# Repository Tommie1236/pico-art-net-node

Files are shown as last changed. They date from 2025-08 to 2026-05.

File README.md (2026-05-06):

# !! working on v2. the main branch is deprecated if you see this message. please go to [the V2 branch](https://github.com/Tommie1236/pico-art-net-node/tree/V2).



# pico-art-net-node

got the idea from the project linked below. took some ideas/parts off it and created my own one 

https://www.techandtransit.com/lighting/pi-pico-artnet-to-dmx-node  
https://github.com/tmingos/Pico-ArtNet-DMX-Node

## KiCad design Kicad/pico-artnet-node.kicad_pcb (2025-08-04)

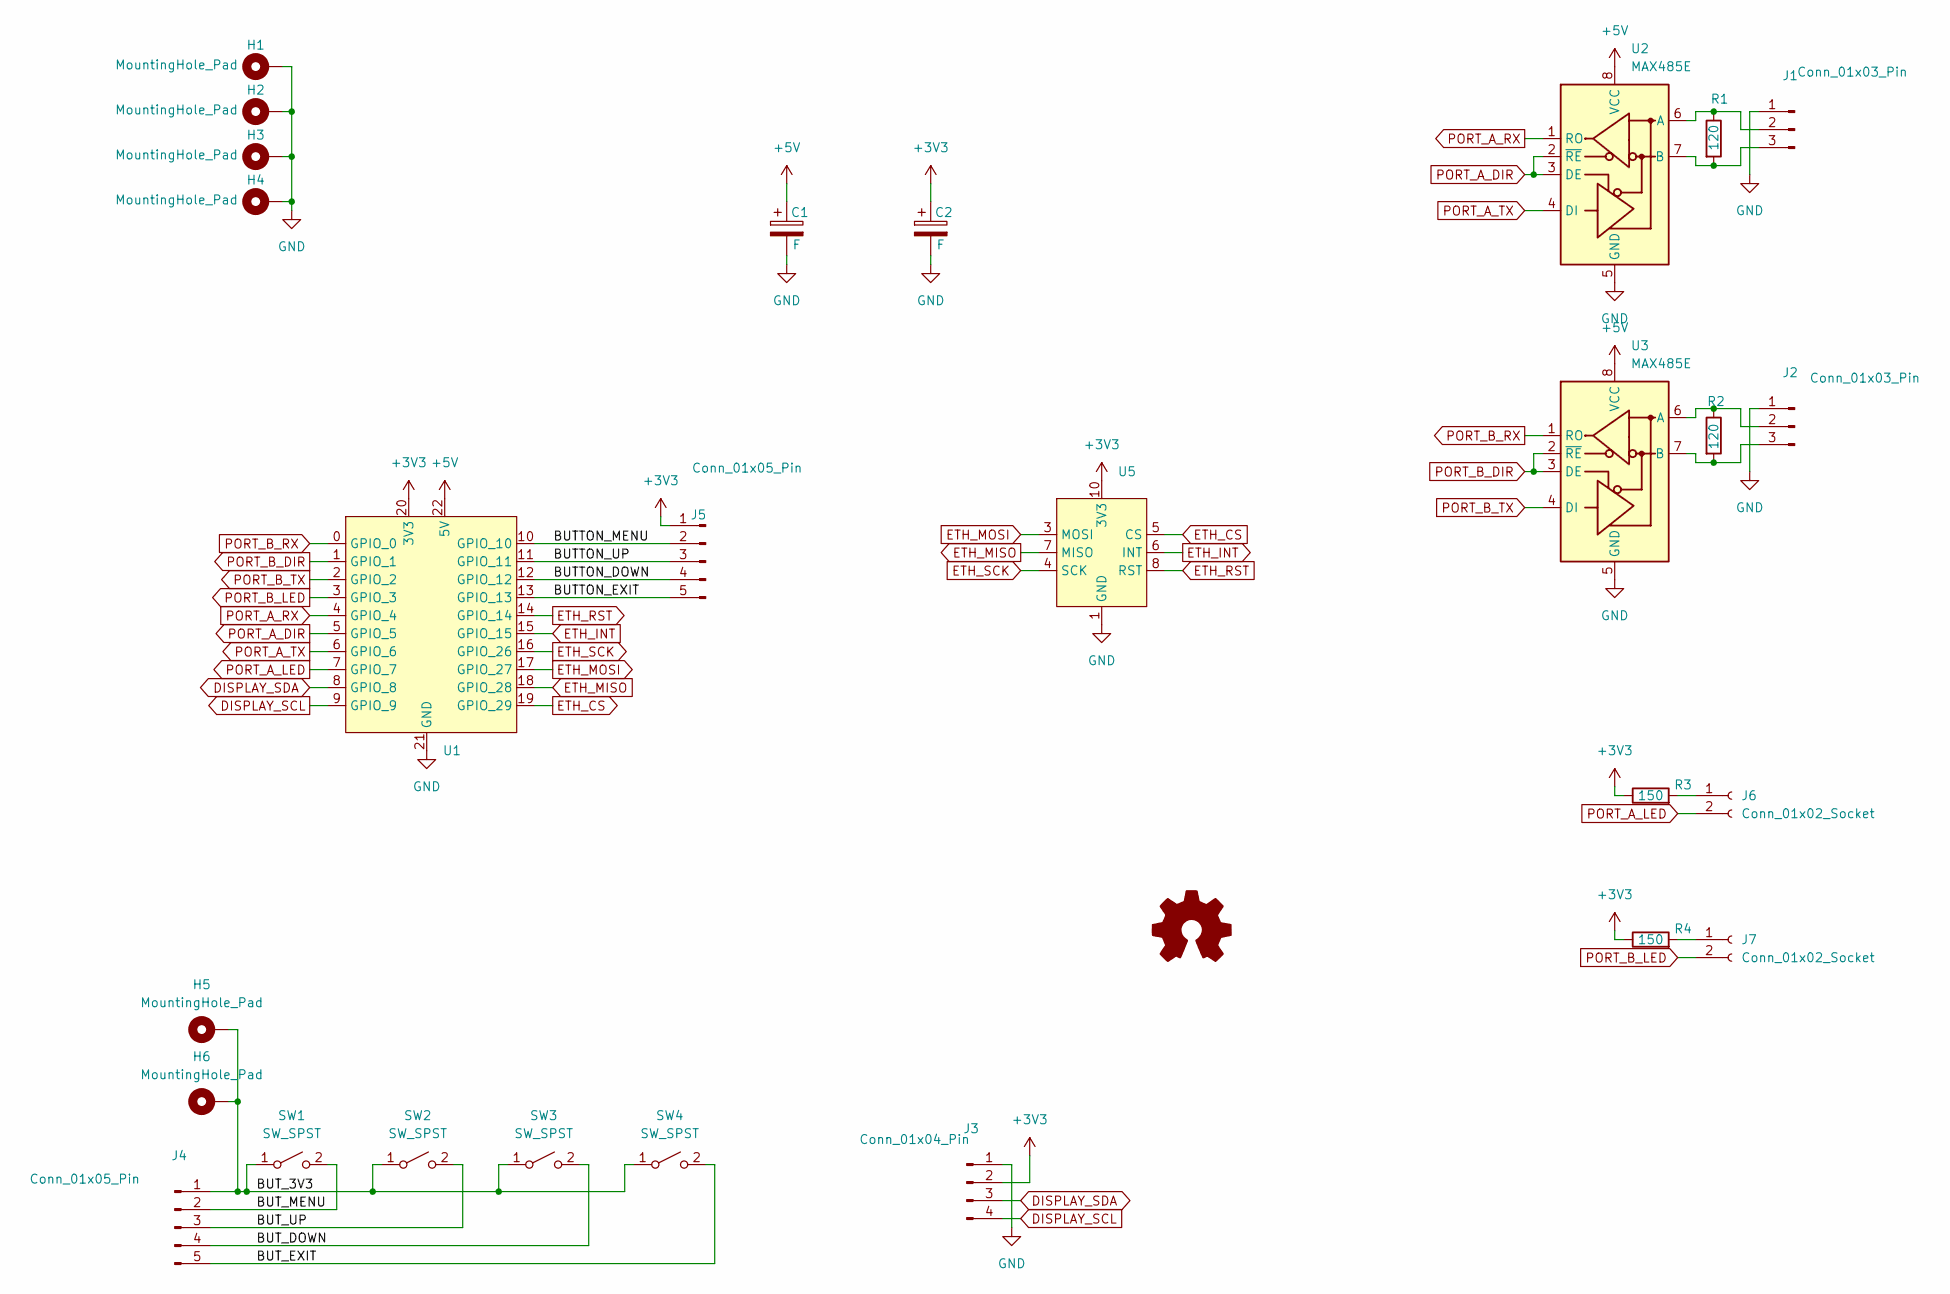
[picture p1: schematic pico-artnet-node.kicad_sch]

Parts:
C1, C2: F; CP_Radial_D5.0mm_P2.50mm
H1, H2, H3, H4, H5, H6: MountingHole_Pad; MountingHole_3.2mm_M3_DIN965_Pad
J1, J2: Conn_01x03_Pin; PinHeader_1x03_P2.54mm_Vertical
J3: Conn_01x04_Pin; PinHeader_1x04_P2.54mm_Vertical
J4, J5: Conn_01x05_Pin; PinHeader_1x05_P2.54mm_Vertical
J6, J7: Conn_01x02_Socket; PinHeader_2x01_P2.54mm_Vertical
R1, R2: 120; R_Axial_DIN0207_L6.3mm_D2.5mm_P2.54mm_Vertical
R3, R4: 150; R_Axial_DIN0207_L6.3mm_D2.5mm_P2.54mm_Vertical
SW1, SW2, SW3, SW4: SW_SPST; SW_PUSH_6mm
SYM2: Logo_Open_Hardware_Small; OSHW-Logo2_14.6x12mm_SilkScreen
U1: RP2040-Zero
U2, U3: MAX485E; DIP-8_W7.62mm
U5: w5500

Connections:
+3V3: C2.1, J3.2, J5.1, R3.1, R4.1, U1.20 (3V3), U5.10 (3V3), U5.11 (3V3)
+5V: C1.1, U1.22 (5V), U2.8 (VCC), U3.8 (VCC)
/BUTTON_DOWN: J5.4, U1.12 (GPIO_12)
/BUTTON_EXIT: J5.5, U1.13 (GPIO_13)
/BUTTON_MENU: J5.2, U1.10 (GPIO_10)
/BUTTON_UP: J5.3, U1.11 (GPIO_11)
/BUT_3V3: H5.1, H6.1, J4.1, SW1.1 (A), SW2.1 (A), SW3.1 (A), SW4.1 (A)
/BUT_DOWN: J4.4, SW3.2 (B)
/BUT_EXIT: J4.5, SW4.2 (B)
/BUT_MENU: J4.2, SW1.2 (B)
/BUT_UP: J4.3, SW2.2 (B)
DISPLAY_SCL: J3.4, U1.9 (GPIO_9)
DISPLAY_SDA: J3.3, U1.8 (GPIO_8)
ETH_CS: U1.19 (GPIO_29), U5.5 (CS)
ETH_INT: U1.15 (GPIO_15), U5.6 (INT)
ETH_MISO: U1.18 (GPIO_28), U5.7 (MISO)
ETH_MOSI: U1.17 (GPIO_27), U5.3 (MOSI)
ETH_RST: U1.14 (GPIO_14), U5.8 (RST)
ETH_SCK: U1.16 (GPIO_26), U5.4 (SCK)
GND: C1.2, C2.2, H1.1, H2.1, H3.1, H4.1, J1.1, J2.1, J3.1, U1.21 (GND), U2.5 (GND), U3.5 (GND), U5.1 (GND), U5.2 (GND), U5.12 (GND)
unnamed: J1.2, R1.1, U2.6 (A)
unnamed: J1.3, R1.2, U2.7 (B)
unnamed: J2.2, R2.1, U3.6 (A)
unnamed: J2.3, R2.2, U3.7 (B)
unnamed: J6.1, R3.2
unnamed: J7.1, R4.2
PORT_A_DIR: U1.5 (GPIO_5), U2.2 (~RE), U2.3 (DE)
PORT_A_LED: J6.2, U1.7 (GPIO_7)
PORT_A_RX: U1.4 (GPIO_4), U2.1 (RO)
PORT_A_TX: U1.6 (GPIO_6), U2.4 (DI)
PORT_B_DIR: U1.1 (GPIO_1), U3.2 (~RE), U3.3 (DE)
PORT_B_LED: J7.2, U1.3 (GPIO_3)
PORT_B_RX: U1.0 (GPIO_0), U3.1 (RO)
PORT_B_TX: U1.2 (GPIO_2), U3.4 (DI)

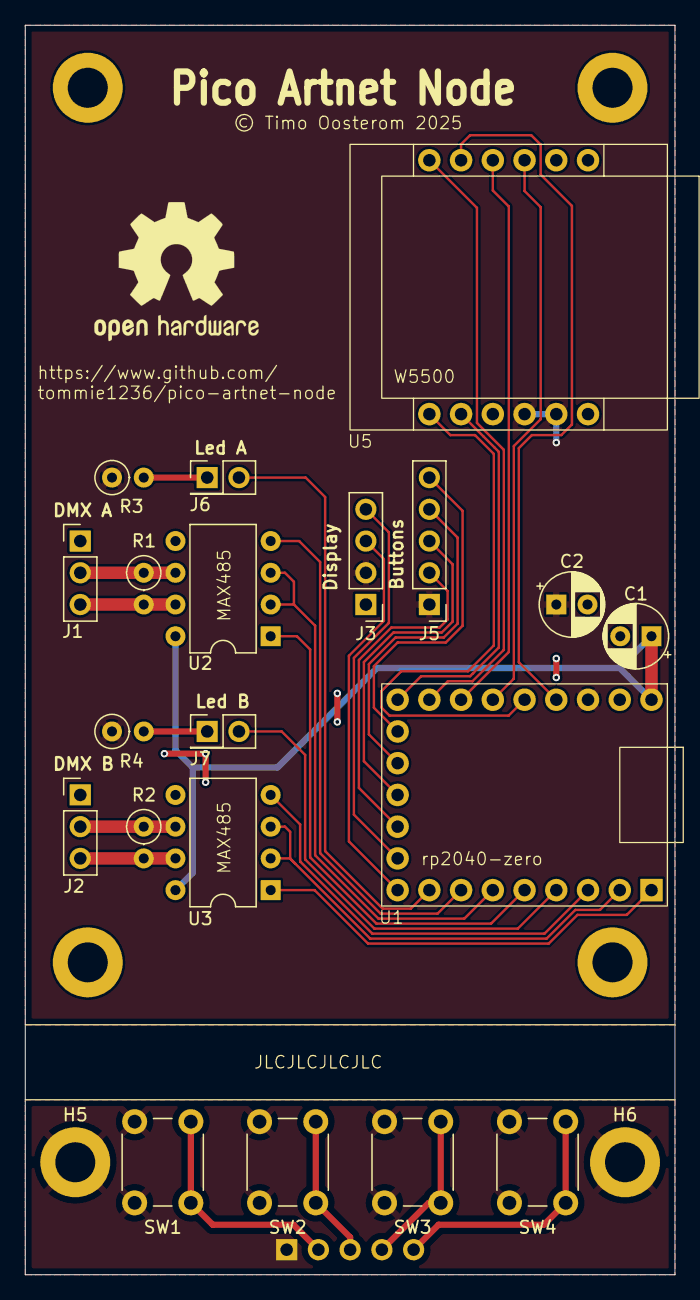
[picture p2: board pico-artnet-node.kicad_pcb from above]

Board: 2 copper layers, 52.0 x 100.0 mm, 28 parts (1 on the bottom side), 34 nets.

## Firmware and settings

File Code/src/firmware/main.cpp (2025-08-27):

#include <stdio.h>
#include <string>
#include <vector>
#include <unordered_map>
#include <variant>
#include <array>
#include <cstdio>

#include "hardware/gpio.h"
#include "hardware/i2c.h"
#include "hardware/spi.h"
#include "pico/stdlib.h"
#include "pico/time.h"
#include "pico/multicore.h"
#include "pico/unique_id.h"

#include "main.h"

#define _WIZCHIP_ W5500
#include "W5500/w5500.h"
#include "wizchip_conf.h"
#include "socket.h"

#include <DmxOutput.h>
//#include <DmxInput.h>
// Dmx input maybe be supported in the future. for now only output.
#include <ssd1306.h>
#include <textRenderer/TextRenderer.h>
#include <shapeRenderer/ShapeRenderer.h>


using namespace pico_ssd1306;

#define FONT font_12x16 

enum MENU_PAGE {
    MAIN,
    NETWORK,
    IP,
    DHCP, 
//    DHCP_STATIC,
    PORTS,
    A,
    A_STATUS,
    A_UNIVERSE,
    B,
    B_STATUS,
    B_UNIVERSE,
    STATUS,
    LOCK            // TODO: Lock/unlock the menu by holding the menu button for 3 seconds.
};

enum PORT_STATUS {
    INPUT,
    OUTPUT,
    DISABLED
};

using ConfigTypes = std::variant<bool, std::array<uint8_t, 4>, uint16_t, PORT_STATUS>;

std::unordered_map<std::string, ConfigTypes> config = {
    {"IP", std::array<uint8_t, 4>{2, 0, 0, 1}},
    {"SUBNET", std::array<uint8_t, 4>{255, 0, 0, 0}},
    {"DHCP", true},
    {"PORT_A_STATUS", PORT_STATUS::OUTPUT},
    {"PORT_A_UNIVERSE", uint16_t(0x0000)},
    {"PORT_B_STATUS", PORT_STATUS::OUTPUT},
    {"PORT_B_UNIVERSE", uint16_t(0x0001)}
};

//DmxOutput dmx_out[2];
//DmxInput  dmx_in[2];


//uint8_t universe_A[UNIVERSE_LENGTH + 1];
//uint8_t universe_B[UNIVERSE_LENGTH + 1];



// Menu structure (https://www.tldraw.com/ro/jS2uV4zSO97DEFvRHu4y5)
//
// MAIN 
//  - Network
//      - ip
//          ip: 002.000.000.001
//          sn: 255.000.000.000
//      - dhcp
//          enable  [ ]
//          disable [x]
//  - Ports
//      - A
//      - B
//          - status
//              output
//              input
//              disabled  
//          - universe
//              net
//              subnet
//              universe
//  - Status ??
//
//


void ip_to_str(std::array<uint8_t, 4> ip, char *ip_str) {
    sprintf(ip_str, "%03d.%03d.%03d.%03d", ip[0], ip[1], ip[2], ip[3]);
}


void init_gpio() {

    uint32_t mask_all = 0;
    mask_all |= (1 << PORT_A_DIR_PIN);
    mask_all |= (1 << PORT_A_LED_PIN);
    mask_all |= (1 << PORT_B_DIR_PIN);
    mask_all |= (1 << PORT_B_LED_PIN);
    mask_all |= (1 << MENU_BUTTON_PIN);
    mask_all |= (1 << UP_BUTTON_PIN);
    mask_all |= (1 << DOWN_BUTTON_PIN);
    mask_all |= (1 << EXIT_BUTTON_PIN);
    mask_all |= (1 << ETH_INT_PIN);
    mask_all |= (1 << ETH_RST_PIN);

    uint32_t mask_inp = 0;
    mask_inp |= (1 << MENU_BUTTON_PIN);
    mask_inp |= (1 << UP_BUTTON_PIN);
    mask_inp |= (1 << DOWN_BUTTON_PIN);
    mask_inp |= (1 << EXIT_BUTTON_PIN);
    mask_inp |= (1 << ETH_INT_PIN);

    // all pins are used so all that arent input are output
    uint32_t mask_out = mask_all & ~mask_inp;

    gpio_init_mask(mask_all);
    gpio_set_dir_in_masked(mask_inp);
    gpio_set_dir_out_masked(mask_out);

    // there is no masked version of pullup/down.
    gpio_pull_up(MENU_BUTTON_PIN);
    gpio_pull_up(UP_BUTTON_PIN);
    gpio_pull_up(DOWN_BUTTON_PIN);
    gpio_pull_up(EXIT_BUTTON_PIN);
    gpio_pull_up(ETH_INT_PIN);     // how add interrupt? change when adding ethernet 

    gpio_put(PORT_A_LED_PIN, 1);
    gpio_put(PORT_B_LED_PIN, 1);
    // set to highest power. seems to not work with less
    gpio_set_drive_strength(PORT_A_LED_PIN, GPIO_DRIVE_STRENGTH_12MA);
    gpio_set_drive_strength(PORT_B_LED_PIN, GPIO_DRIVE_STRENGTH_12MA);
}

void init_oled() {
    i2c_init(i2c0, 1000 * 1000);        
    //i2c_init(i2c0, 3960 * 1000);        // 3.96 MHz. (ssd1306 is max 10Mhz but this is the limit for my module.)

    gpio_set_function(DISPLAY_SDA_PIN, GPIO_FUNC_I2C);
    gpio_set_function(DISPLAY_SCL_PIN, GPIO_FUNC_I2C);

    gpio_pull_up(DISPLAY_SDA_PIN);
    gpio_pull_up(DISPLAY_SCL_PIN);
}

void draw_menu_content(pico_ssd1306::SSD1306 *ssd1306, std::string title, std::vector<std::string> content, bool clear = true) {
    if (clear) {
        ssd1306->clear();
    }
    drawLine(ssd1306, 0, 15, 128, 15);

    // Draw the title
    drawText(ssd1306, FONT, title.c_str(), 0, 0);
    
    // Draw the menu items
    for (uint8_t i = 0; (i < content.size()) & (i < 3); ++i) {
        drawText(ssd1306, FONT, content[i].c_str(), 0, 16 + i * 16);
    }
}

void draw_menu_selected(pico_ssd1306::SSD1306 *ssd1306, uint8_t selected) {
    fillRect(ssd1306, 0, 16 + selected * 16, 128, 31 + selected * 16, WriteMode::INVERT);
}

void draw_menu(
    pico_ssd1306::SSD1306 *ssd1306,
    std::string title,
    std::vector<std::string> content,
    uint8_t selected,
    bool sendBuffer = true
){
    draw_menu_content(ssd1306, title, content);
    draw_menu_selected(ssd1306, selected);

    if (sendBuffer) {
        ssd1306->sendBuffer();
    }
}

void switch_menu(
    MENU_PAGE &current_page,
    MENU_PAGE new_page,
    uint8_t &current_selection
){
    current_page = new_page;
    current_selection = 0;
}


uint8_t wizchip_spi_read(void) {
    uint8_t data;
    spi_read_blocking(ETH_SPI, 0xff, &data, 1);
    return data;
}

void wizchip_spi_write(uint8_t data) {
    spi_write_blocking(ETH_SPI, &data, 1);
}

void wizchip_cs_select(void) {
    gpio_put(ETH_CS_PIN, 0);
}

void wizchip_cs_deselect(void) {
    gpio_put(ETH_CS_PIN, 1);
}


void init_w5500(void) {
    // TODO: check for duplicate pin inits, this is just for a test

    gpio_init(ETH_RST_PIN);
    gpio_set_dir(ETH_RST_PIN, GPIO_OUT);
    gpio_put(ETH_RST_PIN, 0);
    sleep_ms(10);
    gpio_put(ETH_RST_PIN, 1);
    sleep_ms(50);

    spi_init(ETH_SPI, 10 * 1000 * 1000); // 10MHz
    spi_set_format(ETH_SPI, 8, SPI_CPOL_0, SPI_CPHA_0, SPI_MSB_FIRST);
    gpio_set_function(ETH_SCK_PIN, GPIO_FUNC_SPI);
    gpio_set_function(ETH_MOSI_PIN, GPIO_FUNC_SPI);
    gpio_set_function(ETH_MISO_PIN, GPIO_FUNC_SPI);

    gpio_init(ETH_CS_PIN);
    gpio_set_dir(ETH_CS_PIN, GPIO_OUT);
    gpio_put(ETH_CS_PIN, 1);

    reg_wizchip_spi_cbfunc(wizchip_spi_read, wizchip_spi_write);
    reg_wizchip_cs_cbfunc(wizchip_cs_select, wizchip_cs_deselect);

    uint8_t tx_rx_mem[2][8] = { {2,2,2,2,2,2,2,2}, {2,2,2,2,2,2,2,2}};
    
    wizchip_init(tx_rx_mem[0], tx_rx_mem[1]);

    wiz_NetInfo netinfo = {
        .ip = {192, 168, 2, 80},
        .sn = {255, 255, 255, 0},
        .gw = {192, 168, 2, 254},
        .dns = {1, 1, 1, 1},
        .dhcp = NETINFO_STATIC
    };

    // set mac from flash serial to always be unique
    pico_unique_board_id_t id;
    pico_get_unique_board_id(&id);

    memcpy(netinfo.mac, id.id, 6);
    netinfo.mac[0] = (netinfo.mac[0] & 0xfe ) | 0x02;
    
    wizchip_setnetinfo(&netinfo);

}



void main_core_1 () {
    // TODO:
    // handle artnet connection and send the dmx data to the pio's
    // input isn't supported yet. only output.
    DmxOutput dmx_out0 = DmxOutput();
    DmxOutput dmx_out1 = DmxOutput();

    // set port A to output for now
    gpio_put(PORT_A_DIR_PIN, 1);
    gpio_put(PORT_B_DIR_PIN, 1);

    dmx_out0.begin(PORT_A_TX_PIN);
    dmx_out1.begin(PORT_B_TX_PIN);

    socket(0, Sn_MR_UDP, 6454, 0);
    printf("socket connected\n");


    uint8_t buf[600];

    while (true) {

        int32_t len = recvfrom(0, buf, sizeof(buf), NULL, NULL);

        if (len > 0 && len >= 18 && memcmp(buf, "Art-Net\0", 8) == 0) {
            uint16_t opcode = buf[8] | (buf[9] << 8);

            if (opcode == 0x5000) {
                //uint16_t length = (buf[16] << 8) | buf[17];
                uint16_t universe = buf[14] | (buf[15] << 8);

                static uint8_t dmx_frame[513];
                dmx_frame[0] = 0;   // start byte
                memcpy(dmx_frame + 1, buf + 18, 512);

                if (universe == 0) {
                    gpio_put(PORT_A_LED_PIN, 0);    // Dmx Status Led On
                    dmx_out0.write(dmx_frame, 513);
                    while (dmx_out0.busy());
                    gpio_put(PORT_A_LED_PIN, 1);    // Led Off
                } else if (universe == 1) {
                    gpio_put(PORT_B_LED_PIN, 0);    // Dmx Status Led On
                    dmx_out1.write(dmx_frame, 513);
                    while (dmx_out1.busy());
                    gpio_put(PORT_B_LED_PIN, 1);    // Led Off
                }
            }
        }




    }
}

int main () {
    uint16_t universe = 0x0000;
    // Handle user interaction: display/buttons. and the settings.

    stdio_init_all();
    init_gpio();
    init_oled();
    init_w5500();


    SSD1306 display = SSD1306(i2c0, 0x3c, Size::W128xH64);
    display.setOrientation(0);
    display.clear();
    
    multicore_launch_core1(&main_core_1);

    // ---------

    
    MENU_PAGE current_page = MENU_PAGE::MAIN;
    uint8_t current_selection = 0;

    // for editing ip, subnet, universe, etc.
    // keeps the focus on the current window to allow editing of values.
    bool edit_mode = false;

    bool config_changed = false;
    if (config_changed) {
        // remove if implemented
    }
    while (true) {
        // Invert pin values because they are active low.
        // TODO: implement debouncing
        bool button_menu_pressed = !gpio_get(MENU_BUTTON_PIN);
        bool button_up_pressed = !gpio_get(UP_BUTTON_PIN);
        bool button_down_pressed = !gpio_get(DOWN_BUTTON_PIN);
        bool button_exit_pressed = !gpio_get(EXIT_BUTTON_PIN);

        // TODO: refactor the whole menu system. it's still in development but a mess rn.
        // - move the display "printing" to the top of the case.
        // - reorder the button checks to the order: exit, menu, up, down.
        // TODO: switch all menu changes to the menu_switch function.
        // if possible move the debug print to the menu_switch function.
        switch (current_page) {
            case MENU_PAGE::MAIN: if (button_down_pressed) {
                if (current_selection < 2) {
                    current_selection++;
                } else {
                    current_selection = 0;
                }
            } else if (button_up_pressed) {
                    if (current_selection > 0) {
                        current_selection--;
                    } else {
                        current_selection = 2;
                    }
                } else if (button_menu_pressed) {
                    switch (current_selection) {
                        case 0:
                            printf("enter menu network\n");
                            switch_menu(current_page, MENU_PAGE::NETWORK, current_selection);
                            break;
                        case 1:
                            printf("enter menu ports\n");
                            switch_menu(current_page, MENU_PAGE::PORTS, current_selection);
                            break;
                        case 2:
                            printf("enter menu status\n");
                            switch_menu(current_page, MENU_PAGE::STATUS, current_selection);
                            break;
                    }
                } else if (button_exit_pressed) {
                    current_selection = 0;
                }
                draw_menu(&display, "Main:", {"Network", "Ports", "Status"}, current_selection);
                break;

            case MENU_PAGE::NETWORK:
                if (button_down_pressed) {
                    if (current_selection < 1) {
                        current_selection++;
                    } else {
                        current_selection = 0;
                    }
                } else if (button_up_pressed) {
                    if (current_selection > 0) {
                        current_selection--;
                    } else {
                        current_selection = 1;
                    }
                } else if (button_menu_pressed) {
                    switch (current_selection) {
                        case 0:
                            current_page = MENU_PAGE::IP;
                            current_selection = 0;
                            printf("enter menu ip\n"); 
                            break;
                        case 1:
                            current_page = MENU_PAGE::DHCP;
                            current_selection = 0;
                            printf("enter menu dhcp\n");
                            break;
                    }
                } else if (button_exit_pressed) {
                    current_page = MENU_PAGE::MAIN;
                    current_selection = 0;
                    printf("enter menu main\n");
                }
                draw_menu(&display, "Network:", {"IP", "DHCP"}, current_selection);
                break;

            case MENU_PAGE::DHCP:
                if (button_down_pressed) {
                    if (current_selection < 1) {
                        current_selection++;
                    } else {
                        current_selection = 0;
                    } 
                } else if (button_up_pressed) {
                    if (current_selection > 0) {
                        current_selection--;
                    } else {
                        current_selection = 1;
                    }
                } else if (button_menu_pressed) {
                    switch (current_selection) {
                        case 0: // Enable (DHCP)
                            config["DHCP"] = true;
                            config_changed = true;
                            break;
                        case 1: // Disable (DHCP)
                            config["DHCP"] = false;
                            config_changed = true;
                            break;
                    }
                } else if (button_exit_pressed) {
                    current_page = MENU_PAGE::NETWORK;
                    current_selection = 0;
                    printf("enter menu network\n");
                    break;
                }
                draw_menu_content(&display, "DHCP:", {"Enable", "Disable"});
                drawRect(&display, 112, 16, 127, 31);
                drawRect(&display, 112, 32, 127, 47);
                if (std::get<bool>(config["DHCP"])) {   // dhcp enabled
                    drawText(&display, FONT, "x", 114, 15);
                } else {    // dhcp disabled
                    drawText(&display, FONT, "x", 114, 31);
                }
                draw_menu_selected(&display, current_selection);
                display.sendBuffer();
                break;

            case MENU_PAGE::IP: {

                auto ip = std::get<std::array<uint8_t, 4>>(config["IP"]);
                char ip_str[16];
                ip_to_str(ip, ip_str);

                auto subnet = std::get<std::array<uint8_t, 4>>(config["SUBNET"]);
                char subnet_str[16];
                ip_to_str(subnet, subnet_str);

                display.clear();
                draw_menu_content(&display, "IP:", {}, false);

                drawText(&display, font_8x8, "IP Address:", 0, 16);
                drawText(&display, font_8x8, ip_str, 0, 24);
                drawText(&display, font_8x8, "Subnet Mask:", 0, 32);
                drawText(&display, font_8x8, subnet_str, 0, 40);

                // TODO: Disable editing if dhcp enabled 
                if (!edit_mode) {
                    if (button_exit_pressed) {
                        current_page = MENU_PAGE::NETWORK;
                        current_selection = 0;
                        printf("enter menu network\n");
                        break;
                    } else if (button_menu_pressed) {
                        edit_mode = true;
                    } else if (button_down_pressed) {
                        if (current_selection < 1) {
                            current_selection++;
                        } else {
                            current_selection = 0;
                        }
                    } else if (button_up_pressed) {
                        if (current_selection > 0) {
                            current_selection--;
                        } else {
                            current_selection = 1;
                        }
                    }
                    draw_menu_selected(&display, current_selection);
                } else { // edit mode enabled
                    uint8_t edit_selection = 0;
                    while (edit_mode) {
                        button_menu_pressed = !gpio_get(MENU_BUTTON_PIN);
                        button_exit_pressed = !gpio_get(EXIT_BUTTON_PIN);
                        button_down_pressed = !gpio_get(DOWN_BUTTON_PIN);
                        button_up_pressed = !gpio_get(UP_BUTTON_PIN);

                            ip_to_str(ip, ip_str);
                            ip_to_str(subnet, subnet_str);

                            fillRect(&display, 0, 24, 128, 31, WriteMode::SUBTRACT);
                            drawText(&display, font_8x8, ip_str, 0, 24);
                            fillRect(&display, 0, 40, 128, 47, WriteMode::SUBTRACT);
                            drawText(&display, font_8x8, subnet_str, 0, 40);
                            
                        switch (edit_selection) {
                            case 0: // ip part 0                           
                                if (current_selection == 0) {   // ip
                                    fillRect(&display, 0, 24, 24, 31, WriteMode::INVERT);
                                } else if (current_selection == 1) {    // subnet
                                    fillRect(&display, 0, 40, 24, 47, WriteMode::INVERT);
                                }
                                break;
                            case 1: // ip part 1
                                if (current_selection == 0) {   // ip
                                    fillRect(&display, 32, 24, 56, 31, WriteMode::INVERT);
                                } else if (current_selection == 1) {    // subnet
                                    fillRect(&display, 32, 40, 56, 47, WriteMode::INVERT);
                                }
                                break;
                            case 2: // ip part 2
                                if (current_selection == 0) {   // ip
                                    fillRect(&display, 64, 24, 88, 31, WriteMode::INVERT);
                                } else if (current_selection == 1) {    // subnet
                                    fillRect(&display, 64, 40, 88, 47, WriteMode::INVERT);
                                }
                                break;
                            case 3: // ip part 3
                                if (current_selection == 0) {   // ip
                                    fillRect(&display, 96, 24, 120, 31, WriteMode::INVERT);
                                } else if (current_selection == 1) {    // subnet
                                    fillRect(&display, 96, 40, 120, 47, WriteMode::INVERT);
                                }
                                break;
                        }

                            display.sendBuffer();

                        if (button_exit_pressed) {
                            if (current_selection == 0) {
                                config["IP"] = ip;
                                config_changed = true;
                            } else if (current_selection == 1) {
                                config["SUBNET"] = subnet;
                                config_changed = true;
                            }
                            edit_mode = false;
                        } else if (button_menu_pressed) {
                            edit_selection++;
                            if (edit_selection > 3) {
                                edit_selection = 0;
                            }
                        } else if (button_down_pressed) {
                            if (current_selection == 0) {
                                ip[edit_selection]--;
                            } else if (current_selection == 1) {
                                subnet[edit_selection]--;
                            }
                        } else if (button_up_pressed) {
                            if (current_selection == 0) {
                                ip[edit_selection]++;
                            } else if (current_selection == 1) {
                                subnet[edit_selection]++;
                            }
                        }
                    }
                }
                display.sendBuffer();
                break;
            }
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

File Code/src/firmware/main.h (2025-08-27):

// Config file for Pico Art-Net DMX Node
// ©Timo Oosterom 2024

// Config made for a RP2040 Zero. (Pi pico in smaller form factor)
// For full pin functions see: https://datasheets.raspberrypi.com/rp2040/rp2040-datasheet.pdf (Section 1.4.3)
//      
//                   ┏━━━━━┓              
//               ┏━━━┫     ┣━━━┓          
//            5V ┃◎  ┗━━━━━┛  ◎┃ GP0 PORT_A_RX    
//           Gnd ┃■           ◎┃ GP1 PORT_A_DIR    
//           3V3 ┃◎           ◎┃ GP2 PORT_A_TX 
// ETH_CS   GP29 ┃◎           ◎┃ GP3 PORT_A_LED        
// ETH_MOSI GP28 ┃◎           ◎┃ GP4 PORT_B_RX    
// ETH_MISO GP27 ┃◎     □     ◎┃ GP5 PORT_B_DIR    
// ETH_SCK  GP26 ┃◎     ┗GP16 ◎┃ GP6 PORT_B_TX 
// ETH_INT  GP15 ┃◎           ◎┃ GP7 PORT_B_LED
// ETH_RST  GP14 ┃◎ ◎ ◎ ◎ ◎ ◎ ◎┃ GP8 DISPLAY_SDA    
//               ┗━━━━━━━━━━━━━┛
//                  ┃ ┃ ┃ ┃ ┗ GP9    DISPLAY_SCL    
//                  ┃ ┃ ┃ ┗ GP10     MENU_BUTTON    
//                  ┃ ┃ ┗ GP11       UP_BUTTON
//                  ┃ ┗ GP12         DOWN_BUTTON
//                  ┗ GP13           EXIT_BUTTON
//
//  GP17-25 Are available via small pads on the bottom side of the board.

#ifndef MAIN_H
#define MAIN_H

// TODO: add default values for settings that can be changed from the menu

// General
#define UNIVERSE_LENGTH 512

#define PORT_A          0
#define PORT_B          1

// DMX Ports
#define PORT_A_ENABLE   1
#define PORT_A_TX_PIN   6
#define PORT_A_RX_PIN   4
#define PORT_A_DIR_PIN  5
#define PORT_A_LED_PIN  7

#define PORT_B_ENABLE   1
#define PORT_B_TX_PIN   2
#define PORT_B_RX_PIN   0
#define PORT_B_DIR_PIN  1
#define PORT_B_LED_PIN  3

// Display
#define DISPLAY_WIDTH   128
#define DISPLAY_HEIGHT  32 // 64 or 32. don't know what i will go with yet

#define DISPLAY_SDA_PIN  8
#define DISPLAY_SCL_PIN  9

// Buttons/Controls. 
#define MENU_BUTTON_PIN 10  // Menu/Enter
#define UP_BUTTON_PIN   11  // Up
#define DOWN_BUTTON_PIN 12  // Down
#define EXIT_BUTTON_PIN 13  // Exit/Back

// Ethernet (enc28j60)

#define ETH_CS_PIN      29
#define ETH_MOSI_PIN    28
#define ETH_MISO_PIN    27
#define ETH_SCK_PIN     26
#define ETH_INT_PIN     15
#define ETH_RST_PIN     14
#define ETH_SPI         spi1



#endif // MAIN_H

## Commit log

2024-09-08 add ssd1306 lib for ssd1315 i2c display
2024-11-24 fix some unicode characters displaying 2 wide on some systems and breaking the drawing
    [main.h]
2024-11-25 fix typo in main.h
    [main.h]
2024-11-25 change "loading firmware ... to pico" to "RP2040" to make it more general
2024-11-26 create i2c bus scanner because oled didn't have it's address written on it
2024-11-27 moved current_selection reset to right places
    [main.cpp]
2024-11-27 updated build script to automaticly put rp2040 into bootsel mode and reboot after flash
    Yeey, no need to be pressing buttons and pluging/unplugging the usb anymore
2024-12-02 added universe selection for port A.
    compiles correctly but not yet tested on hw
    [main.cpp]
2024-12-02 fix: subnet editing not worky worky
    [main.cpp]
2024-12-08 fix: only load 15lowest bits to config and remove compile error
    [main.cpp]
2024-12-24 updated libs and cmake for libs
    also changed board in build.sh as i am no longer using a pico-w
2025-07-03 fixed indentetion in main.cpp
    [main.cpp]
2025-07-07 started pcb and switched port A/B pins for better layout
    [pico-artnet-node.kicad_pcb, pico-artnet-node.kicad_sch]
2025-07-08 swapped tx and led pins for better pcb layout
    [pico-artnet-node.kicad_pcb, pico-artnet-node.kicad_sch]
2025-07-12 finished pcb
    [pico-artnet-node-B_Cu.gbr, pico-artnet-node-B_Mask.gbr, pico-artnet-node-B_Paste.gbr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]
2025-08-04 swapped miso and mosi lines so they connect correctly
    [pico-artnet-node.kicad_pcb, pico-artnet-node.kicad_sch]
2025-08-04 fix typo and very last version of V1
    [main.cpp]
2025-08-27 updated to 2 universes and fixed some pin definitions
    [main.cpp, main.h]

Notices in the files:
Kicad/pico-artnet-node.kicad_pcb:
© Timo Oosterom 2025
